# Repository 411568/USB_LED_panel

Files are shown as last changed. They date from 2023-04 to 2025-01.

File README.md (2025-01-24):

<p align="center">USB_LED_panel</p>

<h2>🧐 Features</h2>

Small, USB powered LED lamp with up to 6 1W power LEDs. It uses diodes without a radiator, soldered directly onto the PCB. 
The power is delivered by the AP63203 step-down converter with up to 2A output current. The LEDs have forward voltage of about 3.1-3.2V at currents around 200mA, 
that is why I decided to use a simple and cheap 3.3V converter with 1Ohm resistors splitting the power to every LED connected in parallel. 
This way I could also not solder in all of the LEDs, in the end I went with only 3 of them, as I thought it was enough for my usage.

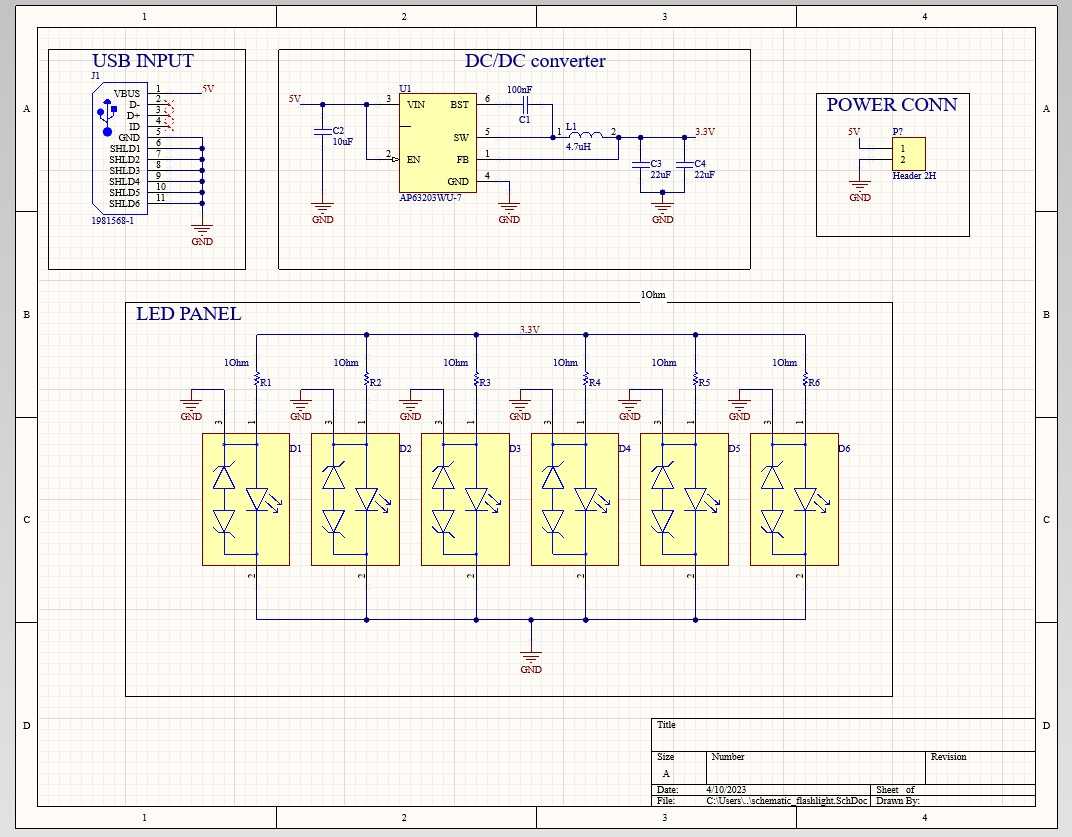
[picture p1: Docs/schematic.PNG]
schematic


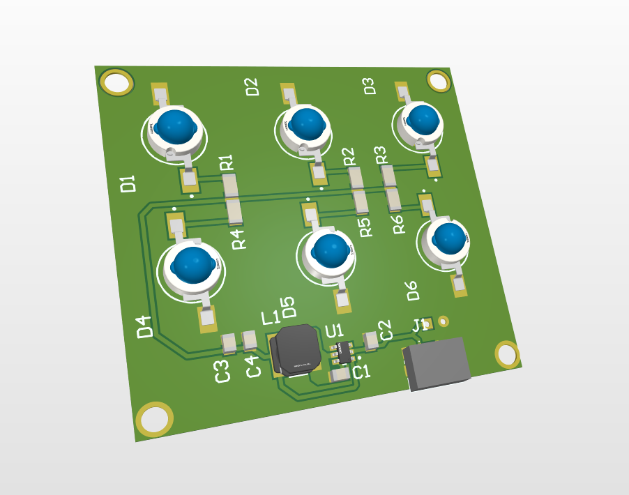
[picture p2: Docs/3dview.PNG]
pcb


<h2>💻 Built with</h2>

The schematic and PCB were both created using Altium Designer.

Parts used in the project:

*  AP63203 step-down converter
*  1 W power LEDs
*  1 Ohm 1206 resistors
*  micro USB connector
*  3D printed enclosure
*  single-sided homemade PCB

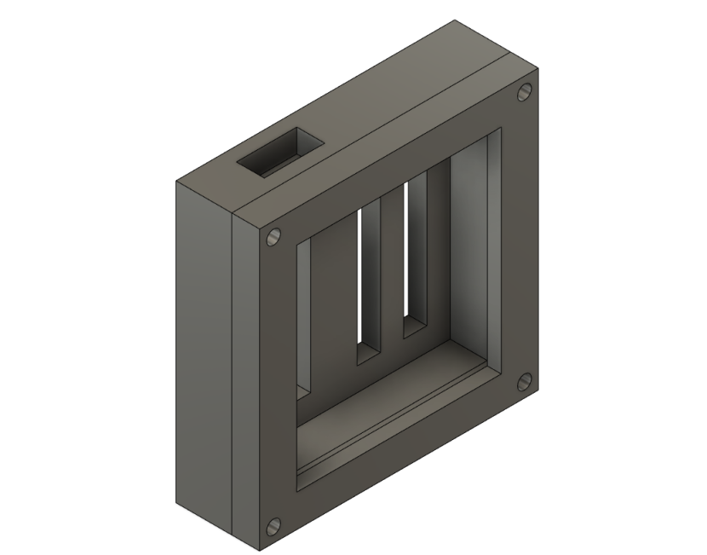
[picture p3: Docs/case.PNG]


<h2>🛡️ License:</h2>

This project is licensed under the MIT License.

<h2> 🙋‍♂️Authors </h2>

- Krzysztof Sikora

<h2>💖Like my work?</h2>

If you have any questions about the project feel free to contact us via email: krzysieksikora717@gmail.com

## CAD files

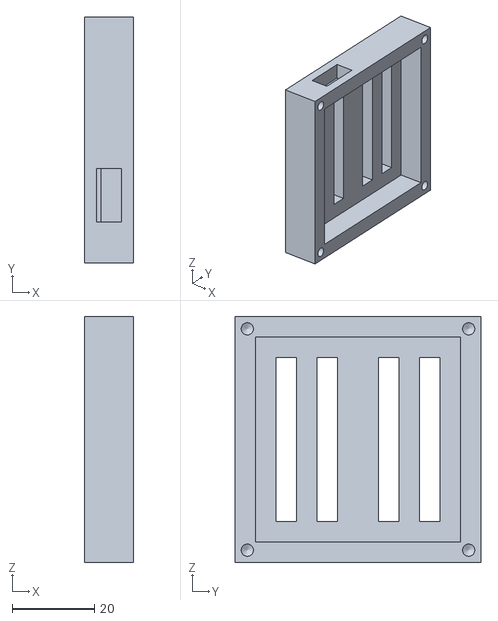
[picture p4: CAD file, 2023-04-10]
3D Models/case_bottom.obj
12.0 x 60.0 x 60.0

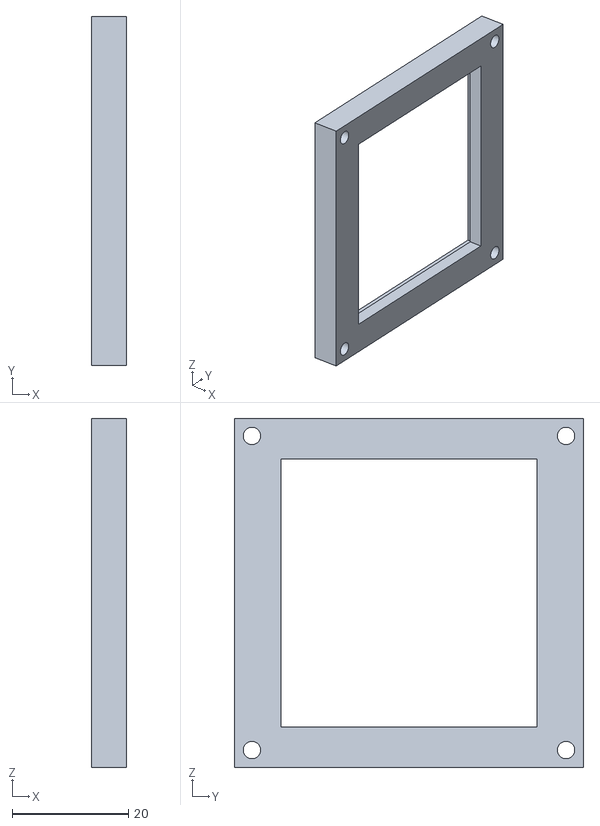
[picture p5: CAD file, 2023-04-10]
3D Models/case_top.obj
6.00 x 60.0 x 60.0

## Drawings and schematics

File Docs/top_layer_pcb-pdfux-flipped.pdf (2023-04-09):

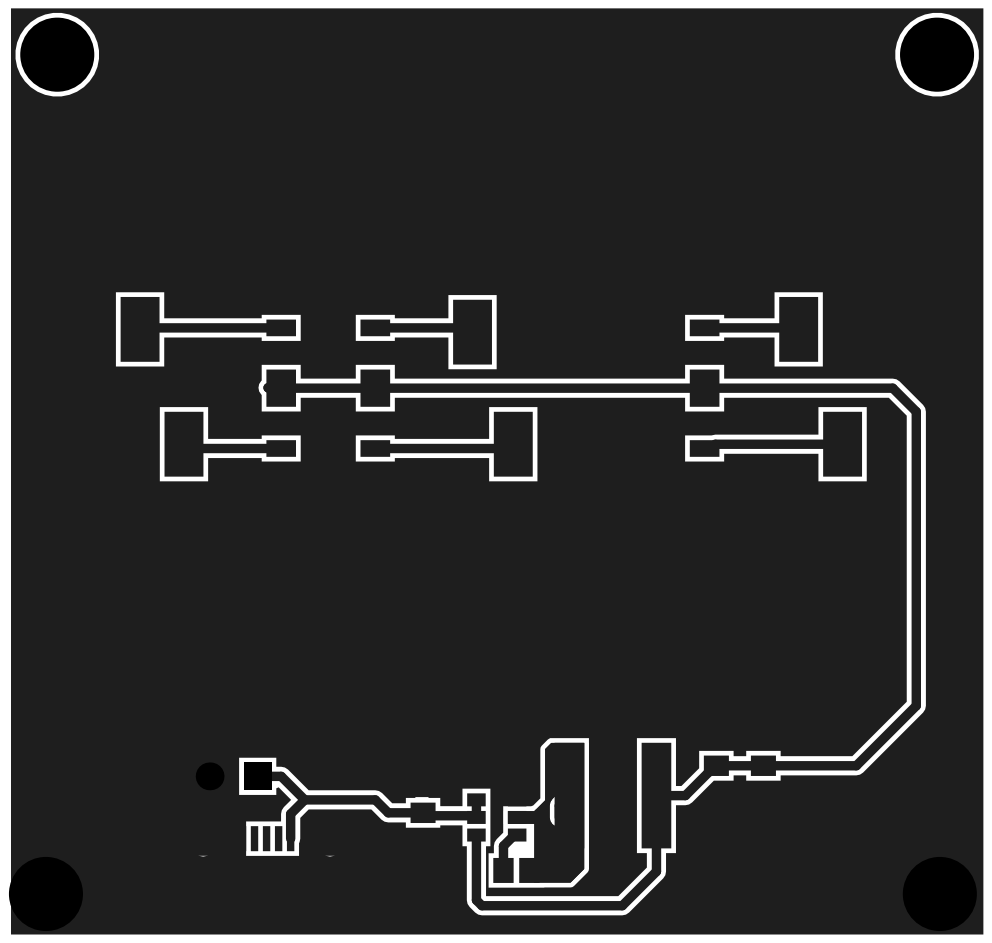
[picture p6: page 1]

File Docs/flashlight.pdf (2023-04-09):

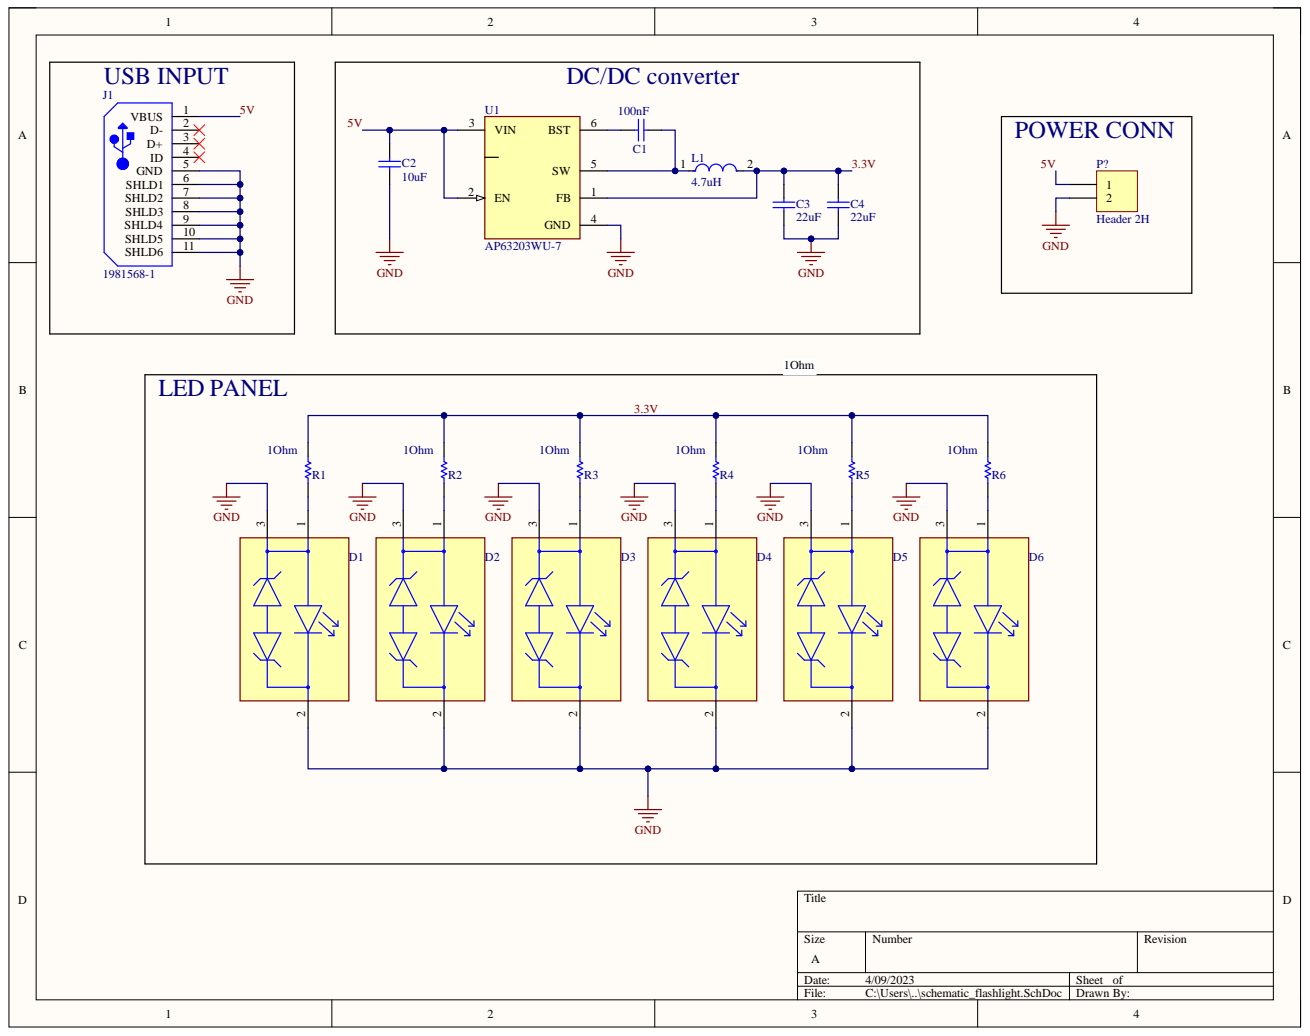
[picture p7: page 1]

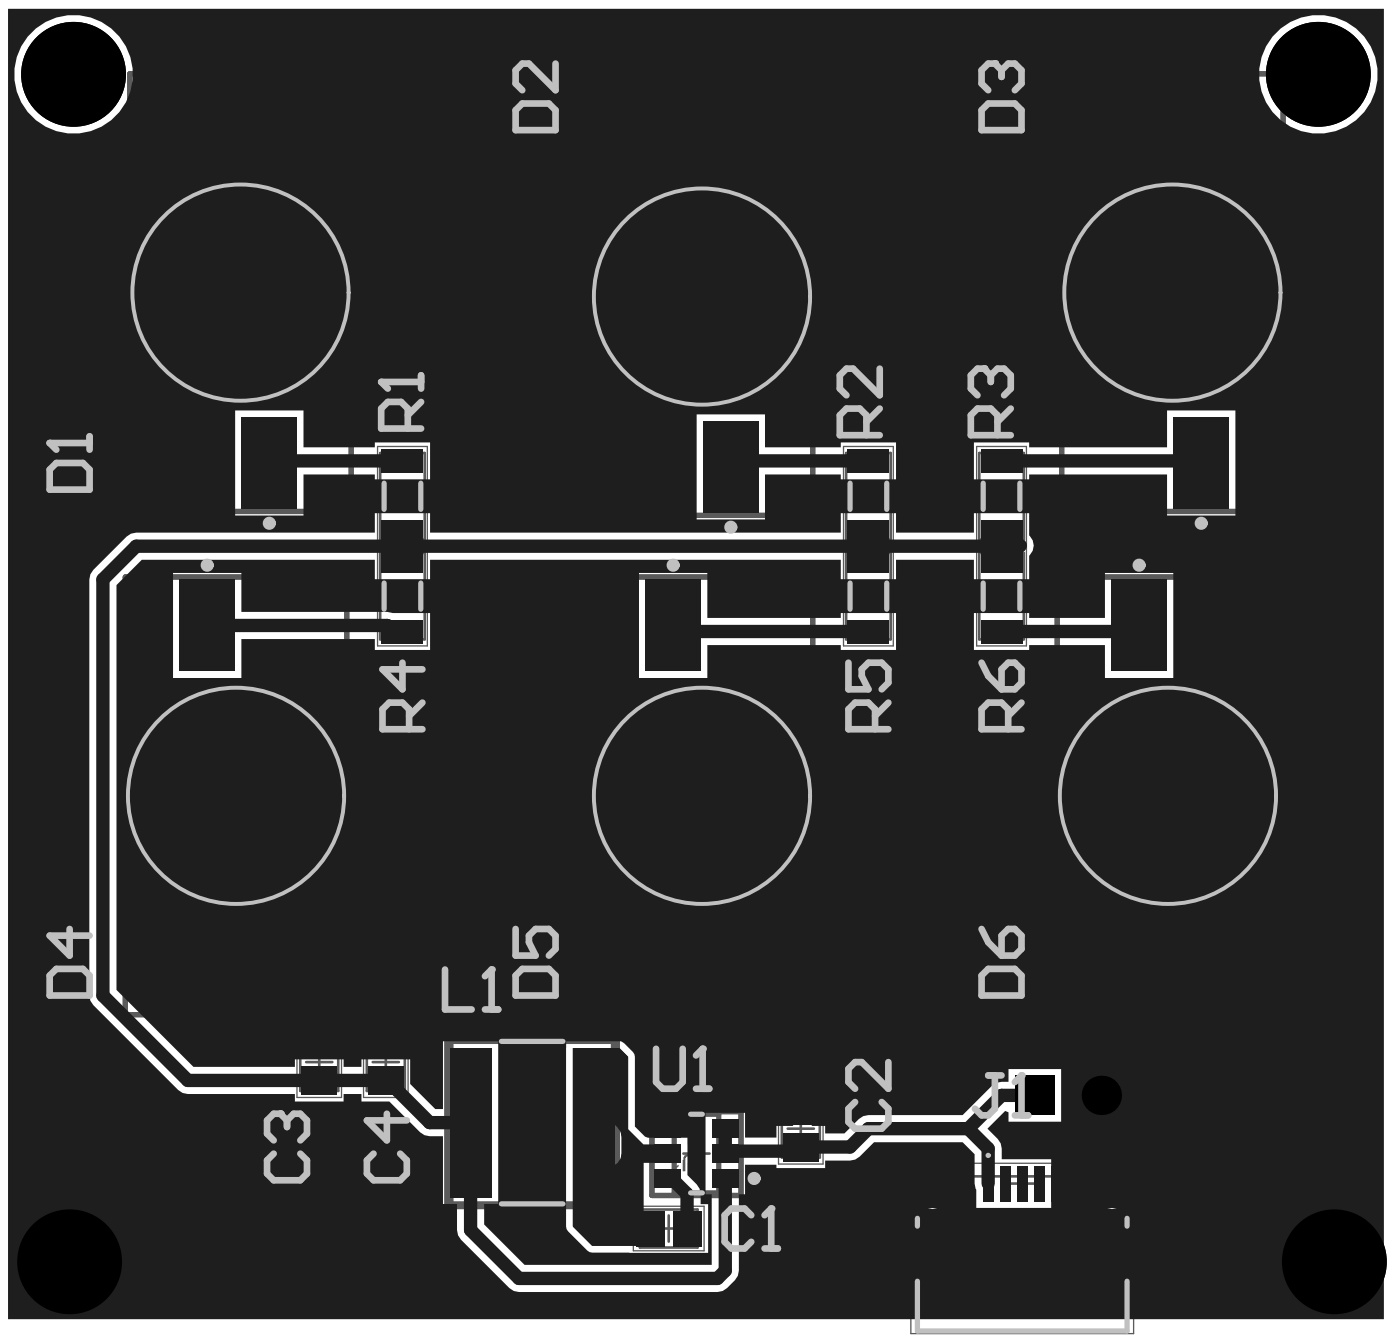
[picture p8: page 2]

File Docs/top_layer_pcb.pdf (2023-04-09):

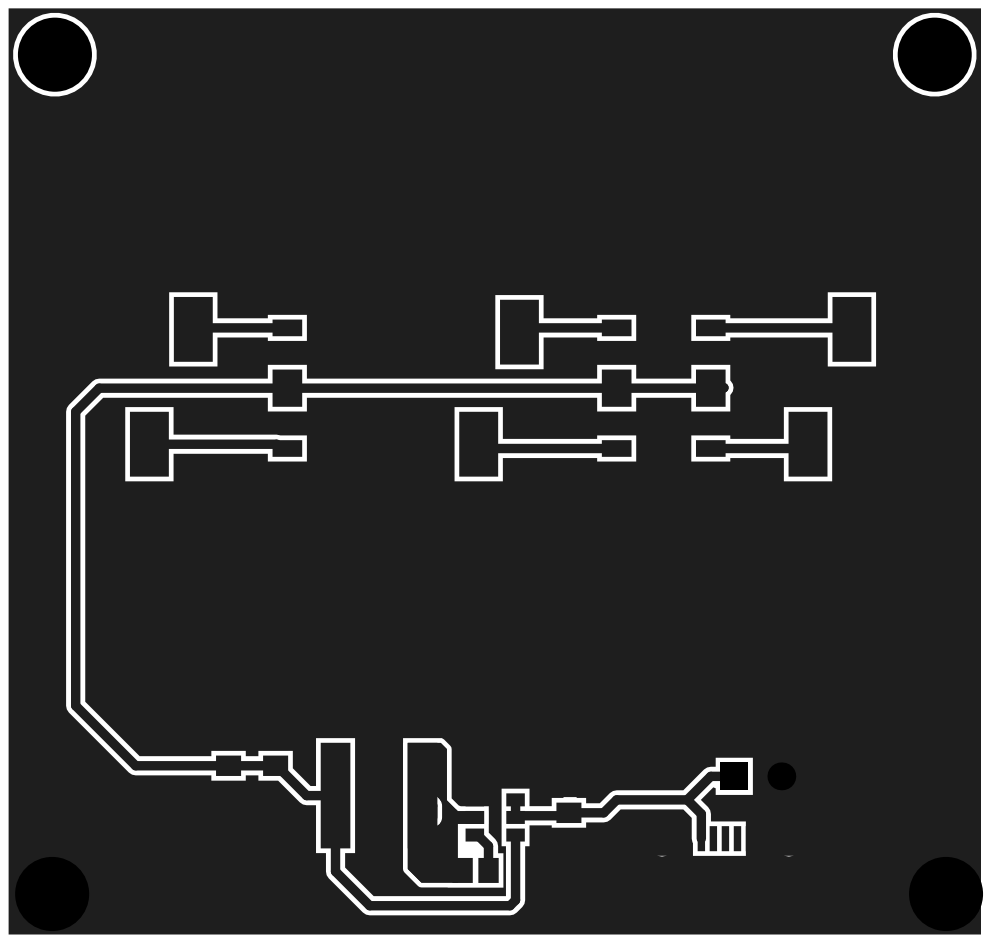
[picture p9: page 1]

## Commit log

2023-04-09 mirrored pcb
2023-04-10 3d models
    [case_bottom.obj, case_top.obj]
2025-01-24 rewritten readme
    [case_bottom.obj, case_top.obj, flashlight.PrjPcb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]
